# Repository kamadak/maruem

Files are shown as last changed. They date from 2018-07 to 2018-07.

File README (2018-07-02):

マルエム松崎ソフトキャリーバッグのキャスター用アダプター
--------------------------------------------------------

   FEATHER WEIGHT ソフトキャリーバッグ (スーツケース) を修理するため、
   キャスターを汎用品に交換するためのアダプター。
   本体の型番は不明。車輪が本体から独立してねじ止めされているタイプ。

3D プリント部
-------------

   使用ソフトウェア: FreeCAD 0.17.13522
   STL 化したときのメッシュ化パラメータ
   -  メッシュ作成オプション: 標準
   -  サーフェス偏差: 0.02 mm
   -  角度の偏差: 10 度

   外形寸法: 80 * 48 * 10 mm
   体積: およそ 16735 mm3

   想定素材: PA12 (MJF)

その他に必要な部品
------------------

   取り付けプレートのねじ穴ピッチが 36 mm * 28 mm のキャスター
   (ハンマーキャスター 420G-R 38mm や iteck KFR-38 キャスター)
   -  車輪直径 38 mm
   -  取り付け穴ピッチ 36 mm * 28 mm
   -  取り付け台座サイズ 46 mm * 38 mm

   ねじ類
   -  ねじ (M4 長さ 10 mm) 4 本 (キャスターとアダプター間)
   -  ねじ (M4 長さ 15 mm) 2 本 (アダプターと本体間)
      (原物の部品では、はめあい長さが 8-9 mm くらい。)
   -  ナット 4 個
   -  ワッシャー (外径 9 mm) 6 個

Copyright and License
---------------------

   Copyright (c) 2018 KAMADA Ken'ichi.
   All rights reserved.

   Redistribution and use in source and binary forms, with or without
   modification, are permitted provided that the following conditions
   are met:
   1. Redistributions of source code must retain the above copyright
      notice, this list of conditions and the following disclaimer.
   2. Redistributions in binary form must reproduce the above copyright
      notice, this list of conditions and the following disclaimer in the
      documentation and/or other materials provided with the distribution.

   THIS SOFTWARE IS PROVIDED BY THE AUTHOR AND CONTRIBUTORS ``AS IS'' AND
   ANY EXPRESS OR IMPLIED WARRANTIES, INCLUDING, BUT NOT LIMITED TO, THE
   IMPLIED WARRANTIES OF MERCHANTABILITY AND FITNESS FOR A PARTICULAR PURPOSE
   ARE DISCLAIMED.  IN NO EVENT SHALL THE AUTHOR OR CONTRIBUTORS BE LIABLE
   FOR ANY DIRECT, INDIRECT, INCIDENTAL, SPECIAL, EXEMPLARY, OR CONSEQUENTIAL
   DAMAGES (INCLUDING, BUT NOT LIMITED TO, PROCUREMENT OF SUBSTITUTE GOODS
   OR SERVICES; LOSS OF USE, DATA, OR PROFITS; OR BUSINESS INTERRUPTION)
   HOWEVER CAUSED AND ON ANY THEORY OF LIABILITY, WHETHER IN CONTRACT, STRICT
   LIABILITY, OR TORT (INCLUDING NEGLIGENCE OR OTHERWISE) ARISING IN ANY WAY
   OUT OF THE USE OF THIS SOFTWARE, EVEN IF ADVISED OF THE POSSIBILITY OF
   SUCH DAMAGE.

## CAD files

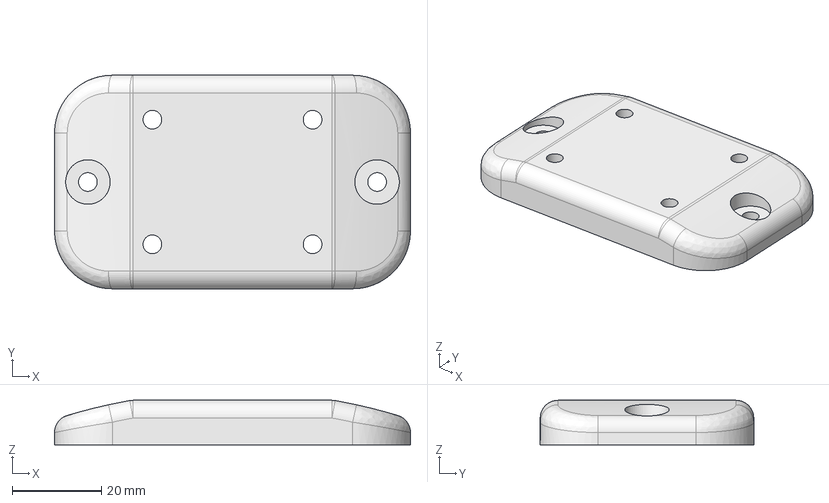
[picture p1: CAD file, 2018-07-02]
caster_adapter.FCStd
80.0 x 48.0 x 10.0 mm

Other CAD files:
caster_adapter.stl

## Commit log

2018-06-05 Add a 3D model of the caster adapter for Feather Weight roller bag.
    [caster_adapter.FCStd, caster_adapter.stl]
2018-07-02 Revise the caster adapter model.
    - Reduce the width from 50 mm to 48 mm to avoid the conflict with
    the piping.
    - Adjust the height from 11 mm to 10 mm.
    - Reduce the wall thickness from 3 mm to 2 mm for the material cost.
    - Increase the diameter of the screw holes from 4 mm to 4.2 mm.
    - Fill in the project information.
    [caster_adapter.FCStd, caster_adapter.stl]
